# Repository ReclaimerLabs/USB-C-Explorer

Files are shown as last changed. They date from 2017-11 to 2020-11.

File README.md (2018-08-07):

# Introduction

The USB-C Explorer is a development board with everything needed to start working with USB Type-C. It contains a USB-C port controller and Power Delivery PHY chip, a microcontroller, and several options for user interaction. Here are the hardware features.

* [SAMD21E17A](https://www.microchip.com/wwwproducts/en/ATSAMD21E17) microcontroller
* [FUSB302B](http://www.onsemi.com/PowerSolutions/product.do?id=FUSB302B) USB PD PHY
* OLED Display
* Capacitive-sense slider
* Power header (up to 5 Amps)
* Debug port (UART and/or GPIO)
* SWD connector (Tag-Connect)
* Reset and User Buttons
* Onboard regulator, input up to 20 V.

# More Detail

The default firmware will identify as a USB Power Delivery Sink and list out all power capabilities from a corresponding Source. It will then request the highest power option. This voltage will be available on the power header. 

The default firmware also includes a USB bootloader. If you hold the User Button during reset, it will show up as a USB Mass Storage Device with a single file "FLASH.BIN". Copy the file to inspect the application firmware. Delete it and replace it with a new .bin file to rewrite the firmware. No programming cable is required.

To use the Single Wire Debug (SWD) function for live debugging, you will need a Tag-Connect TC2050-IDC-NL "plug of nails" cable and clip. You can then use an adapter to something like a Segger or J-Link.

This design is open source under an MIT license. All hardware designs, documentation, and firmware are freely available. You can find all design files at this github repository. I welcome feedback, so please let me know what you think. In particular, help with firmware would be appreciated. 

# Where to Buy

You can purchase a board [here](https://www.tindie.com/products/ReclaimerLabs/usb-c-explorer/). 

# Questions, Comments, and Contributions

Pull requests are welcome. If you have questions or comments, you can email me directly at jason@reclaimerlabs.com.

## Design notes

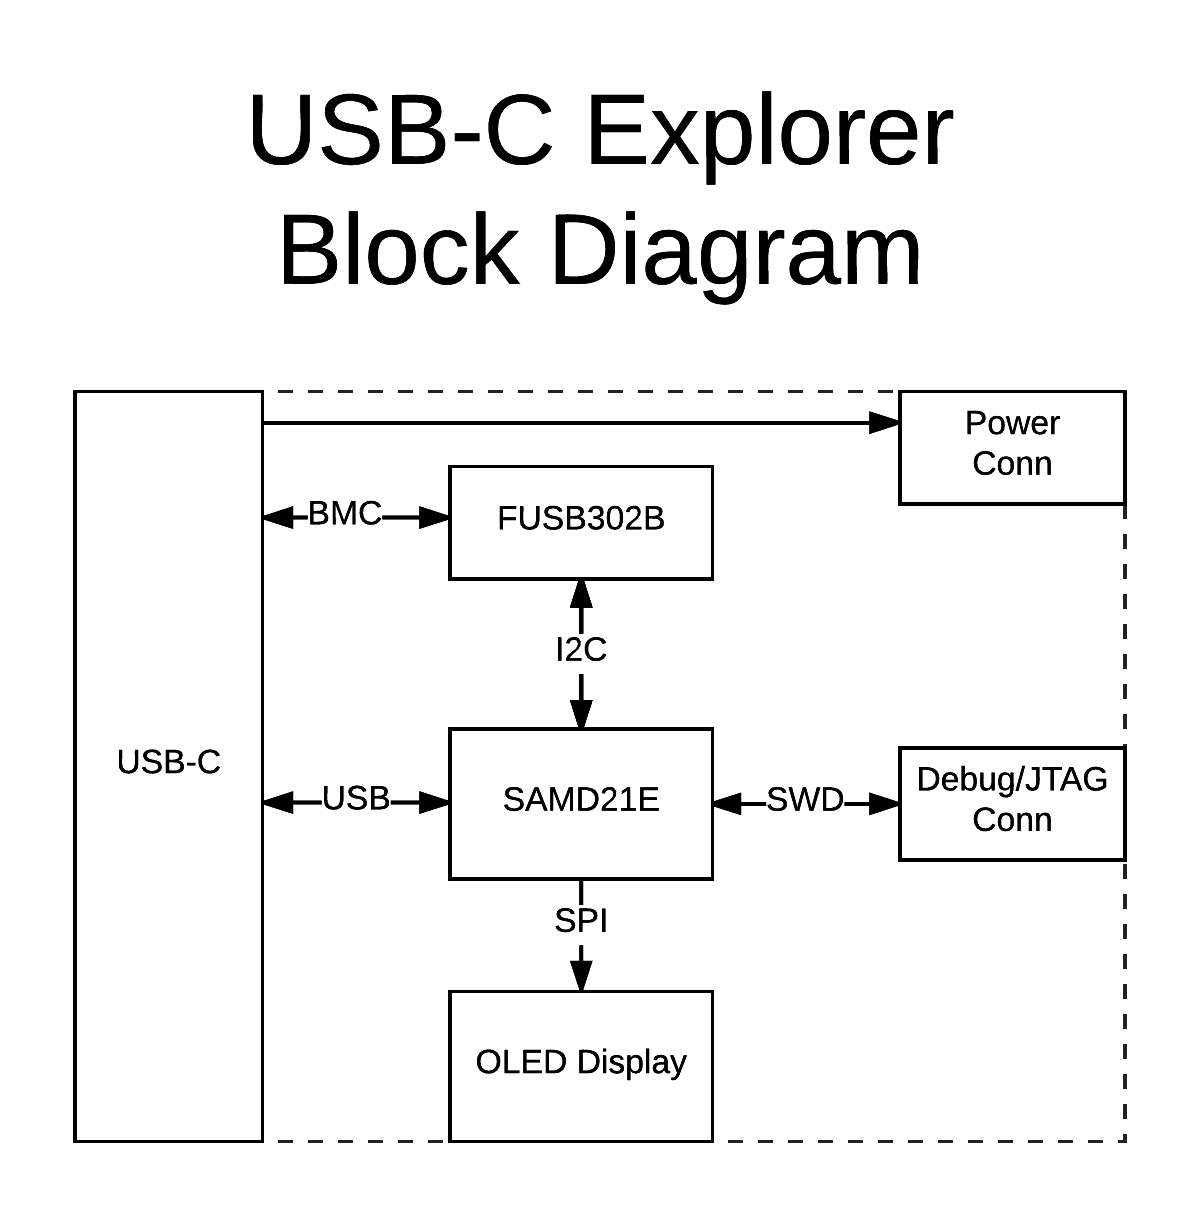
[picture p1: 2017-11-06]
electrical/img/USB-C Explorer Block Diagram.png

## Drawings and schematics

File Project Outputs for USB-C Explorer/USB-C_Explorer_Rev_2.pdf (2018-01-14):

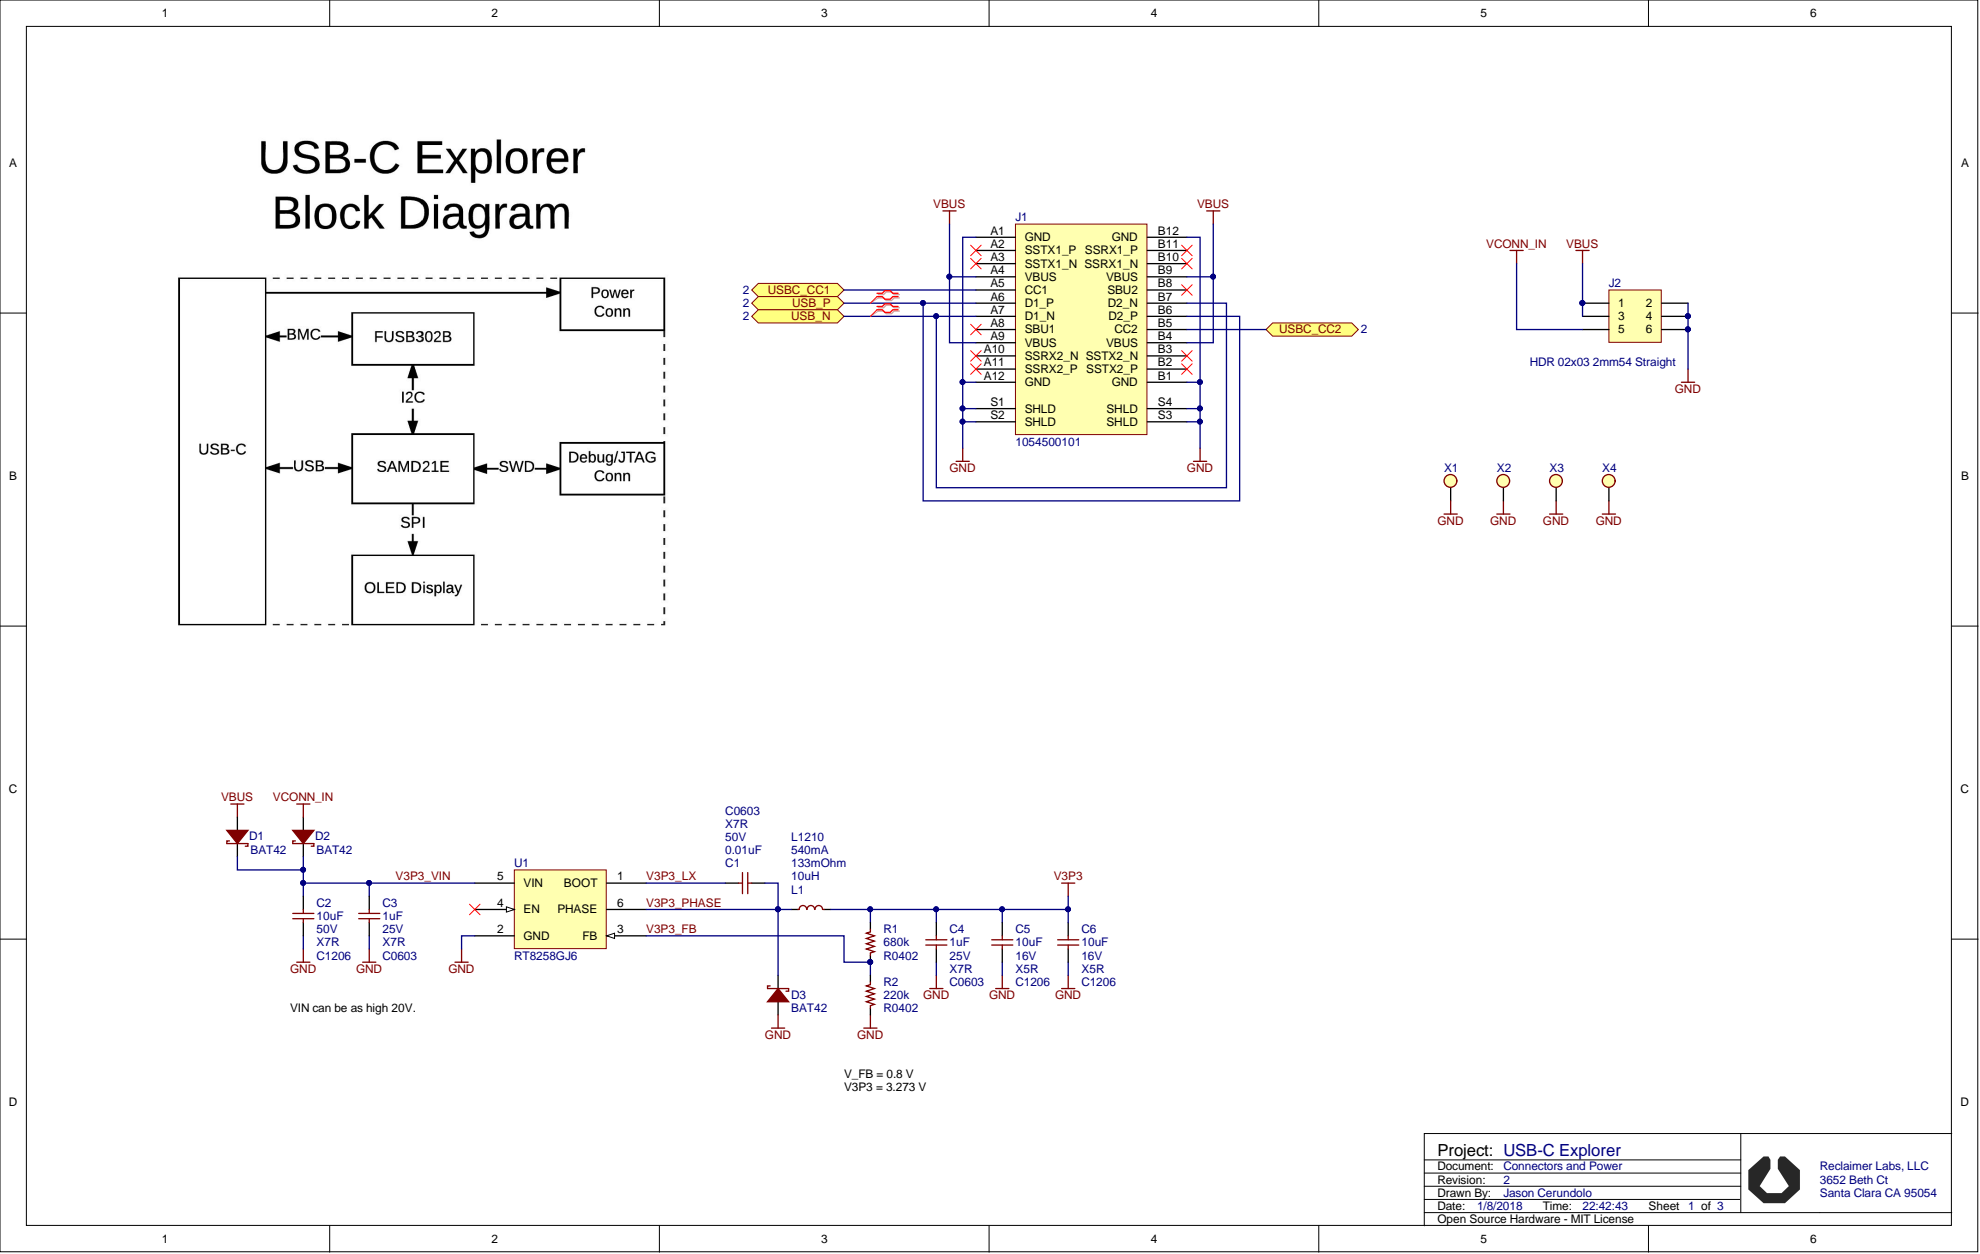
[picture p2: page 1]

VIN can be as high 20V.

Project:
Document: Connectors and Power
Revision:
Drawn By:
Date:
Open Source Hardware - MIT License

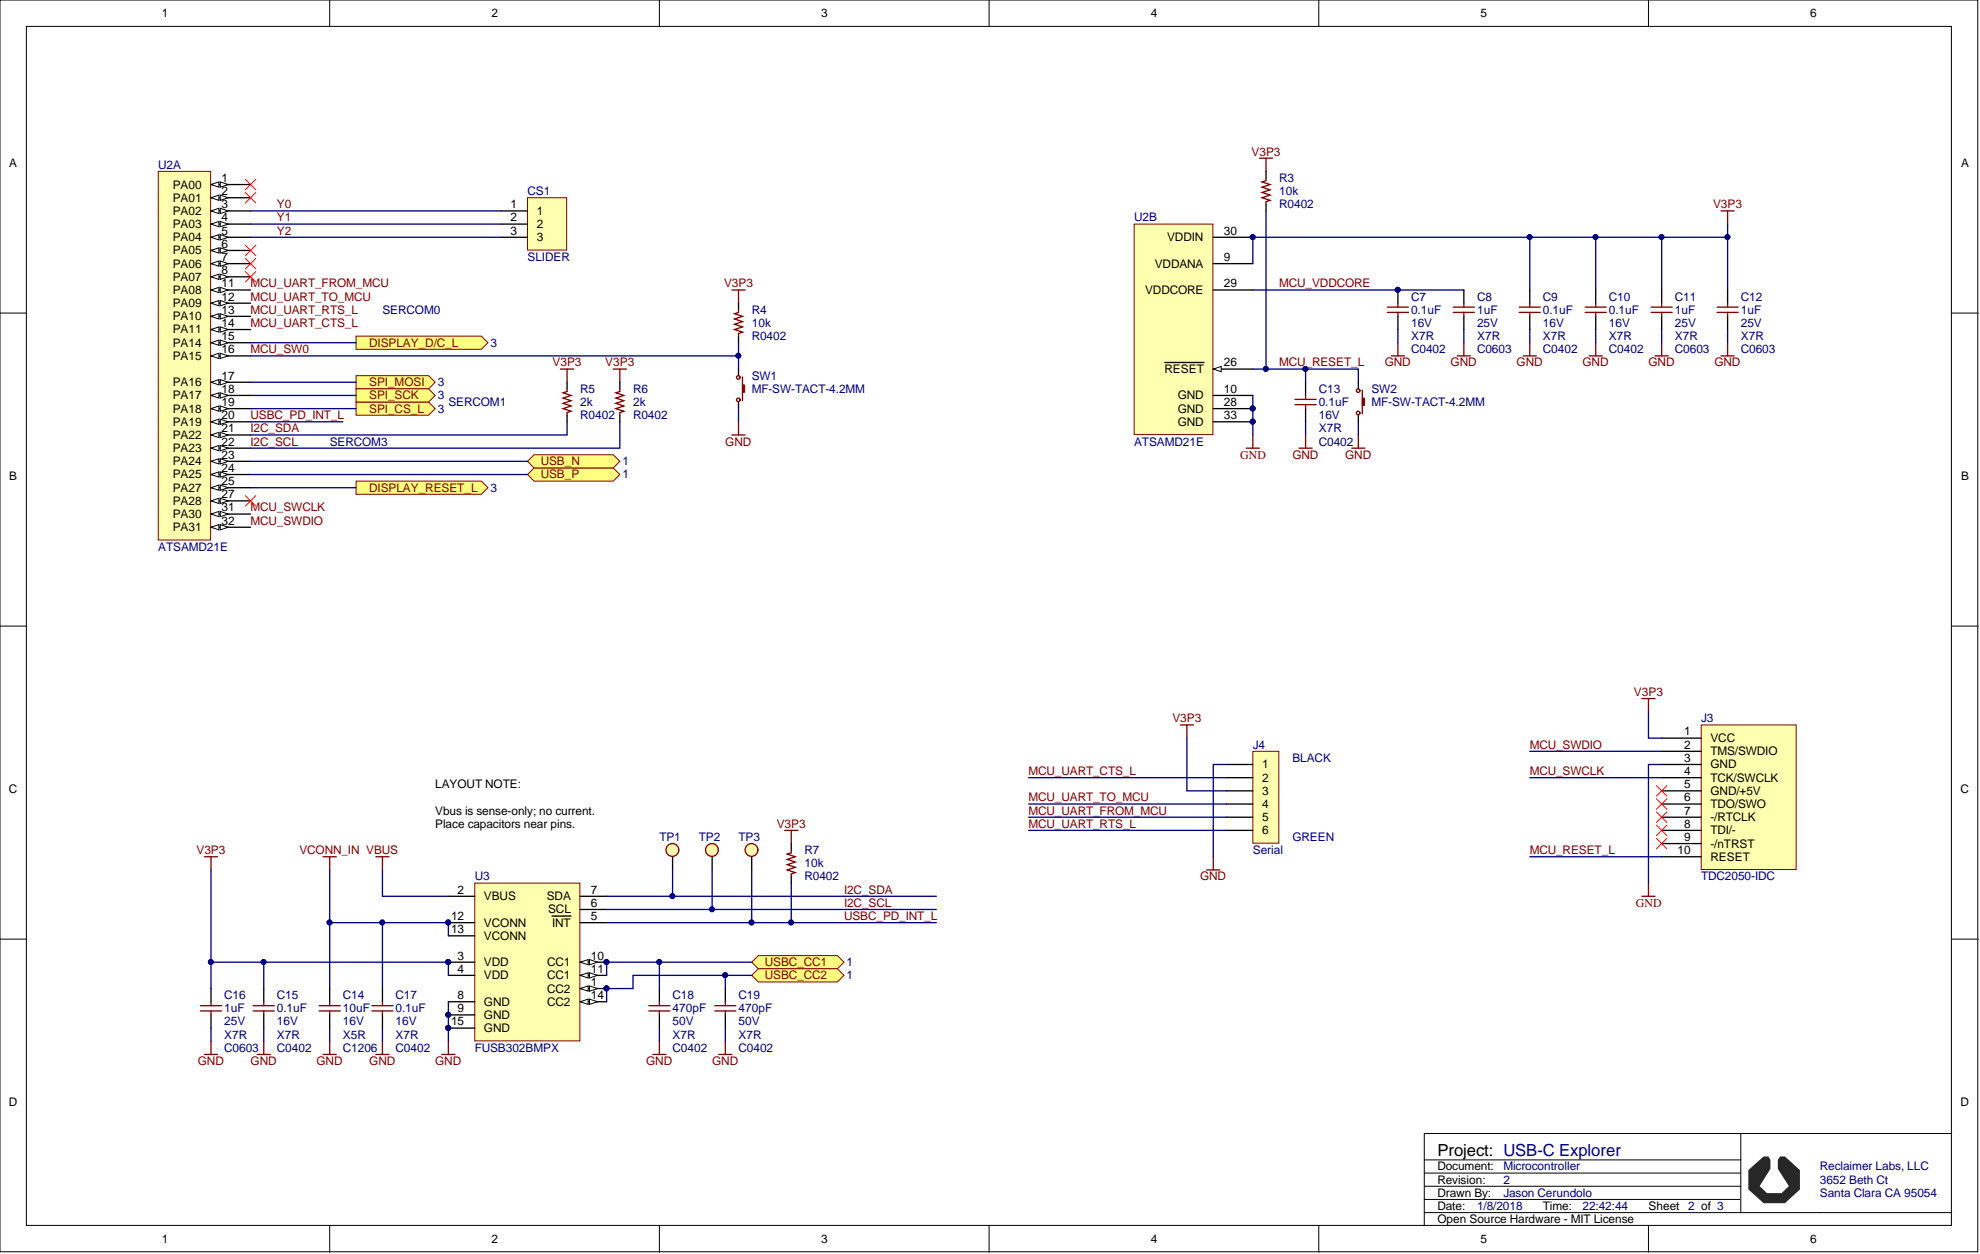
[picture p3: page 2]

Vbus is sense-only; no current.
Place capacitors near pins.

VDD 3

GND 8

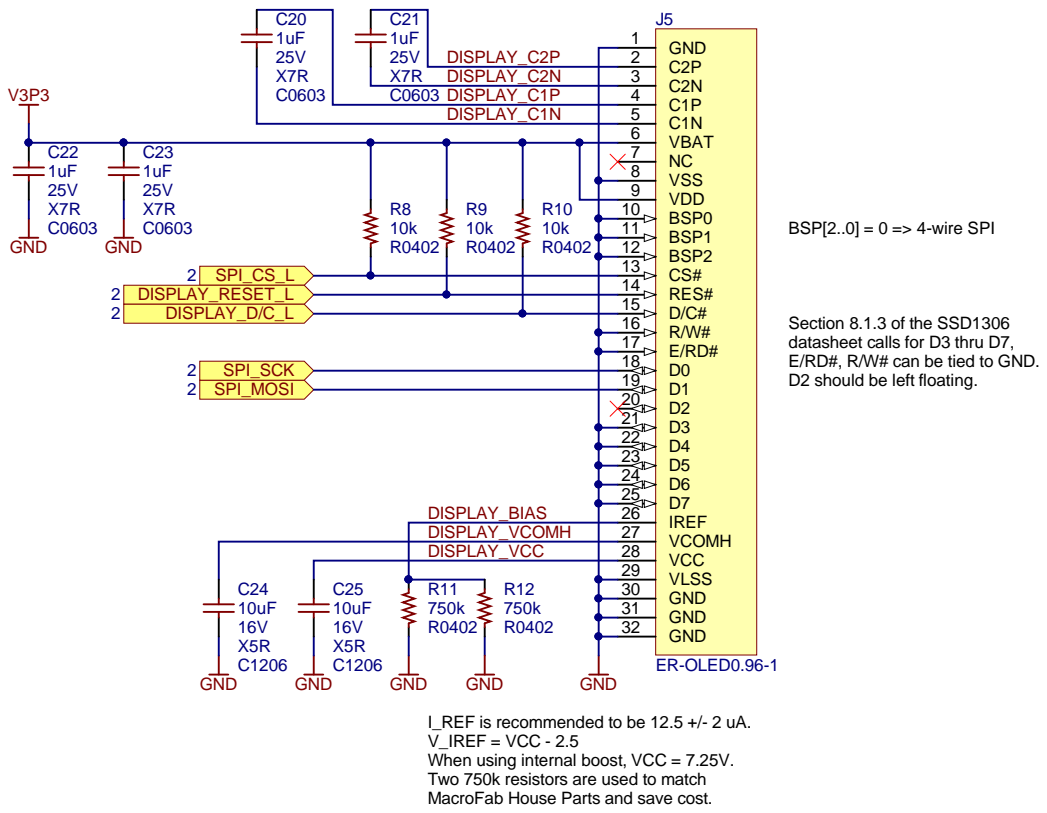
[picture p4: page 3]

C0603 | X7R DISPLAY_C2N | C2N 3

VDD 9

datasheet calls for D3 thru D7,
E/RD#, R/W# can be tied to GND.
D2 should be left floating.

IREF 26

DISPLAY_VCOMH | | | VCOMH 27
DISPLAY_VCC | | | VCC 28

VLSS 29
GND 30
GND 31
GND 32

I_REF is recommended to be 12.5 +/- 2 uA.
V_IREF = VCC - 2.5
When using internal boost, VCC = 7.25V.
Two 750k resistors are used to match
MacroFab House Parts and save cost.

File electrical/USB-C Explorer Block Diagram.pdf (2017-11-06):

# USB-C Explorer Block Diagram

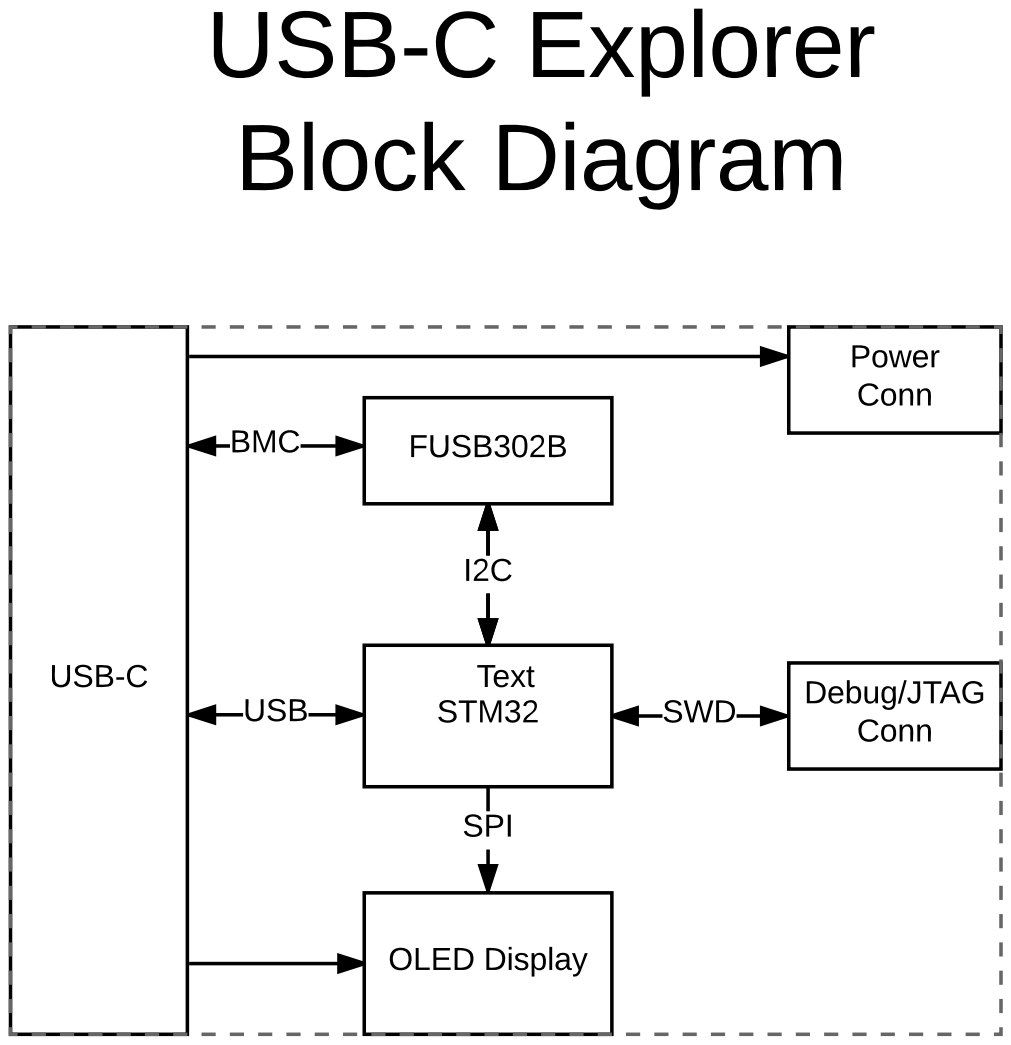
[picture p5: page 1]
USB-C; STM32; FUSB302B; OLED Display; Debug/JTAG Conn; Power Conn; BMC; USB; SWD; SPI; Text

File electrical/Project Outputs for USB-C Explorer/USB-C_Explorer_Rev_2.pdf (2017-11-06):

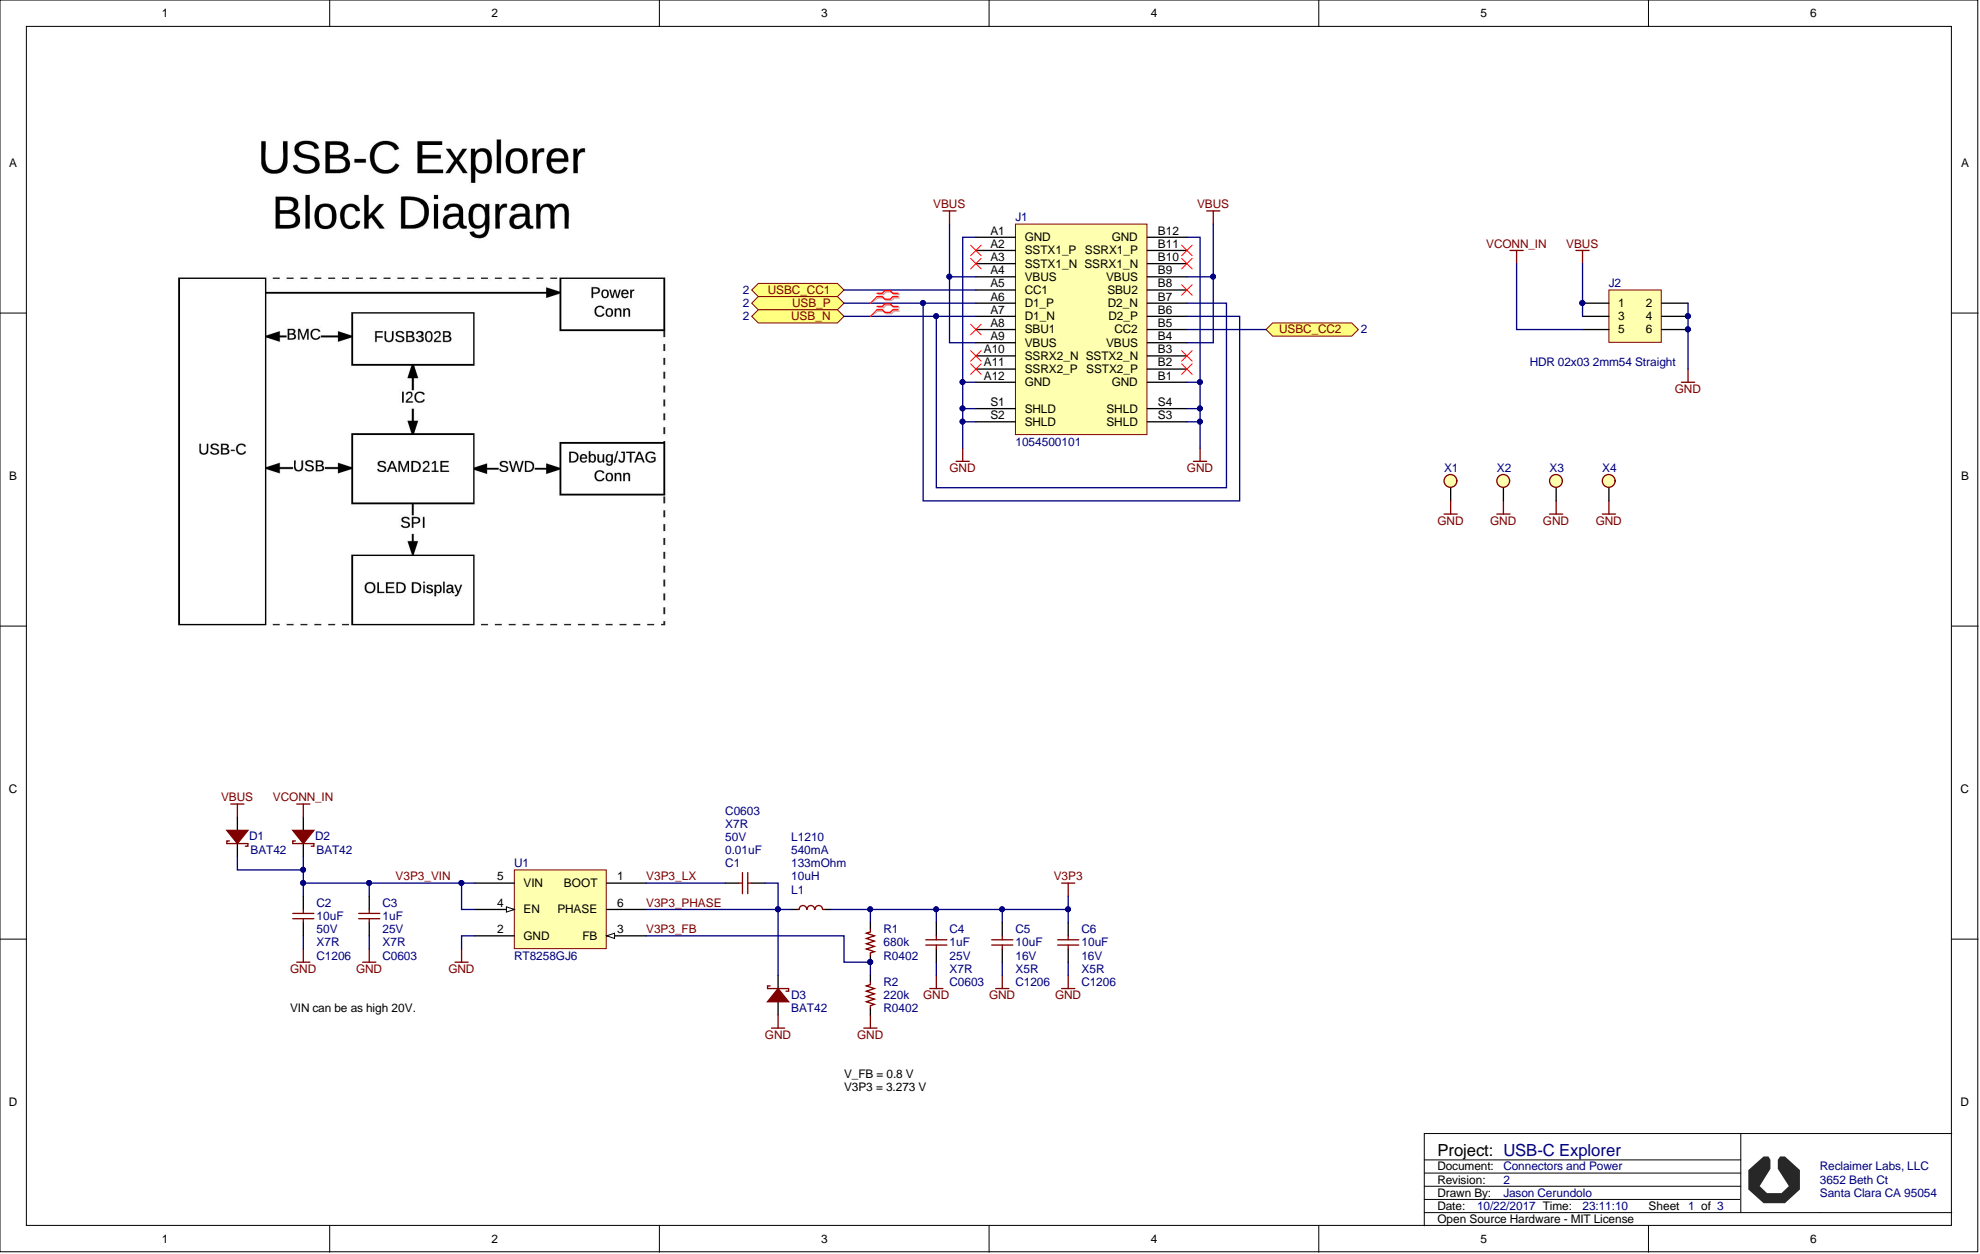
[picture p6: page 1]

VIN can be as high 20V.

Project:
Document: Connectors and Power
Revision:
Drawn By:
Date:
Open Source Hardware - MIT License

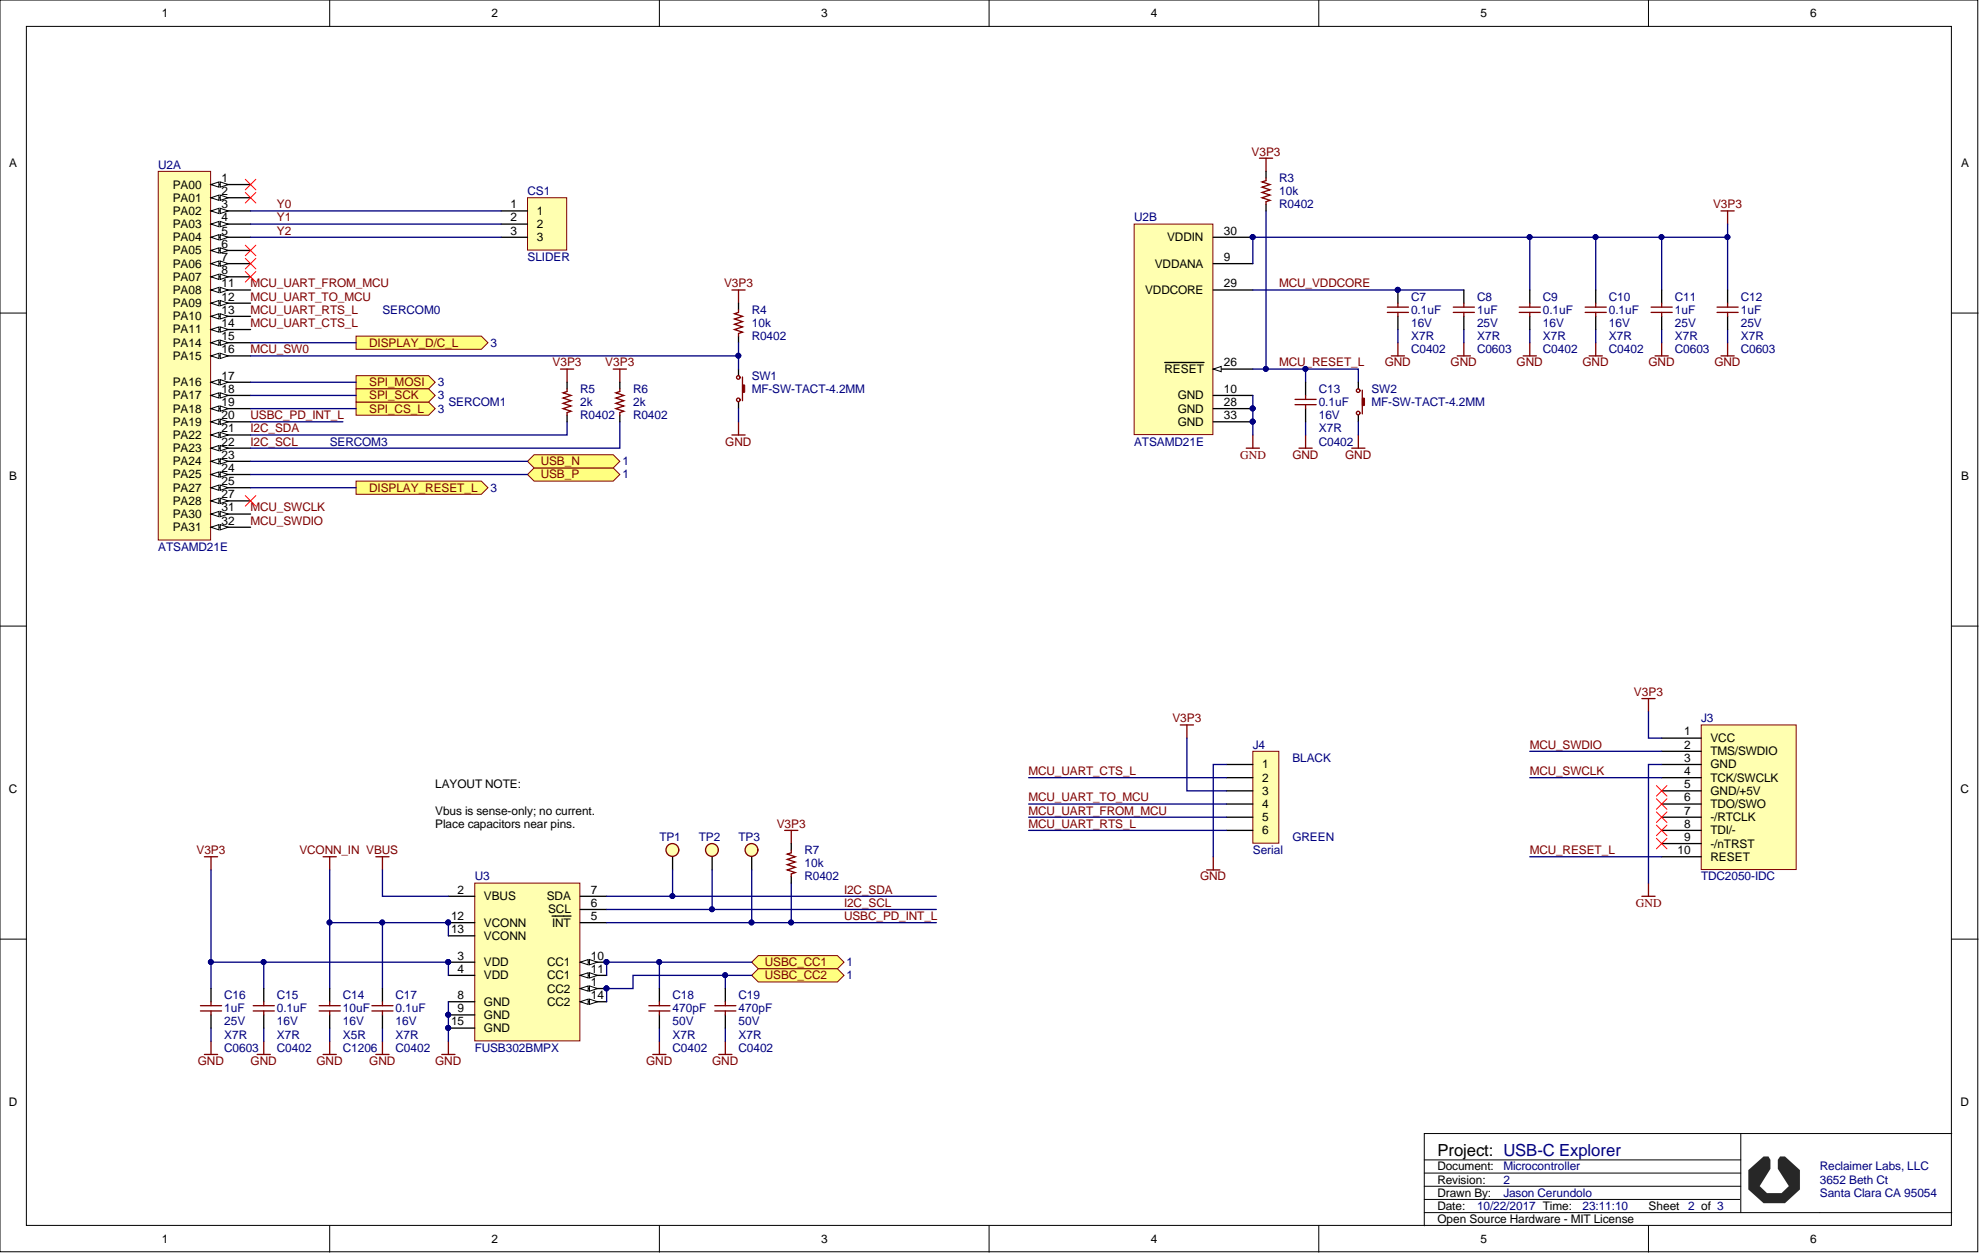
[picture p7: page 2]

Vbus is sense-only; no current.
Place capacitors near pins.

VDD 3

GND 8


C0603 | X7R DISPLAY_C2N | C2N 3

VDD 9

datasheet calls for D3 thru D7,
E/RD#, R/W# can be tied to GND.
D2 should be left floating.

IREF 26

DISPLAY_VCOMH | | | VCOMH 27
DISPLAY_VCC | | | VCC 28

VLSS 29
GND 30
GND 31
GND 32

I_REF is recommended to be 12.5 +/- 2 uA.
V_IREF = VCC - 2.5
When using internal boost, VCC = 7.25V.
Two 750k resistors are used to match
MacroFab House Parts and save cost.

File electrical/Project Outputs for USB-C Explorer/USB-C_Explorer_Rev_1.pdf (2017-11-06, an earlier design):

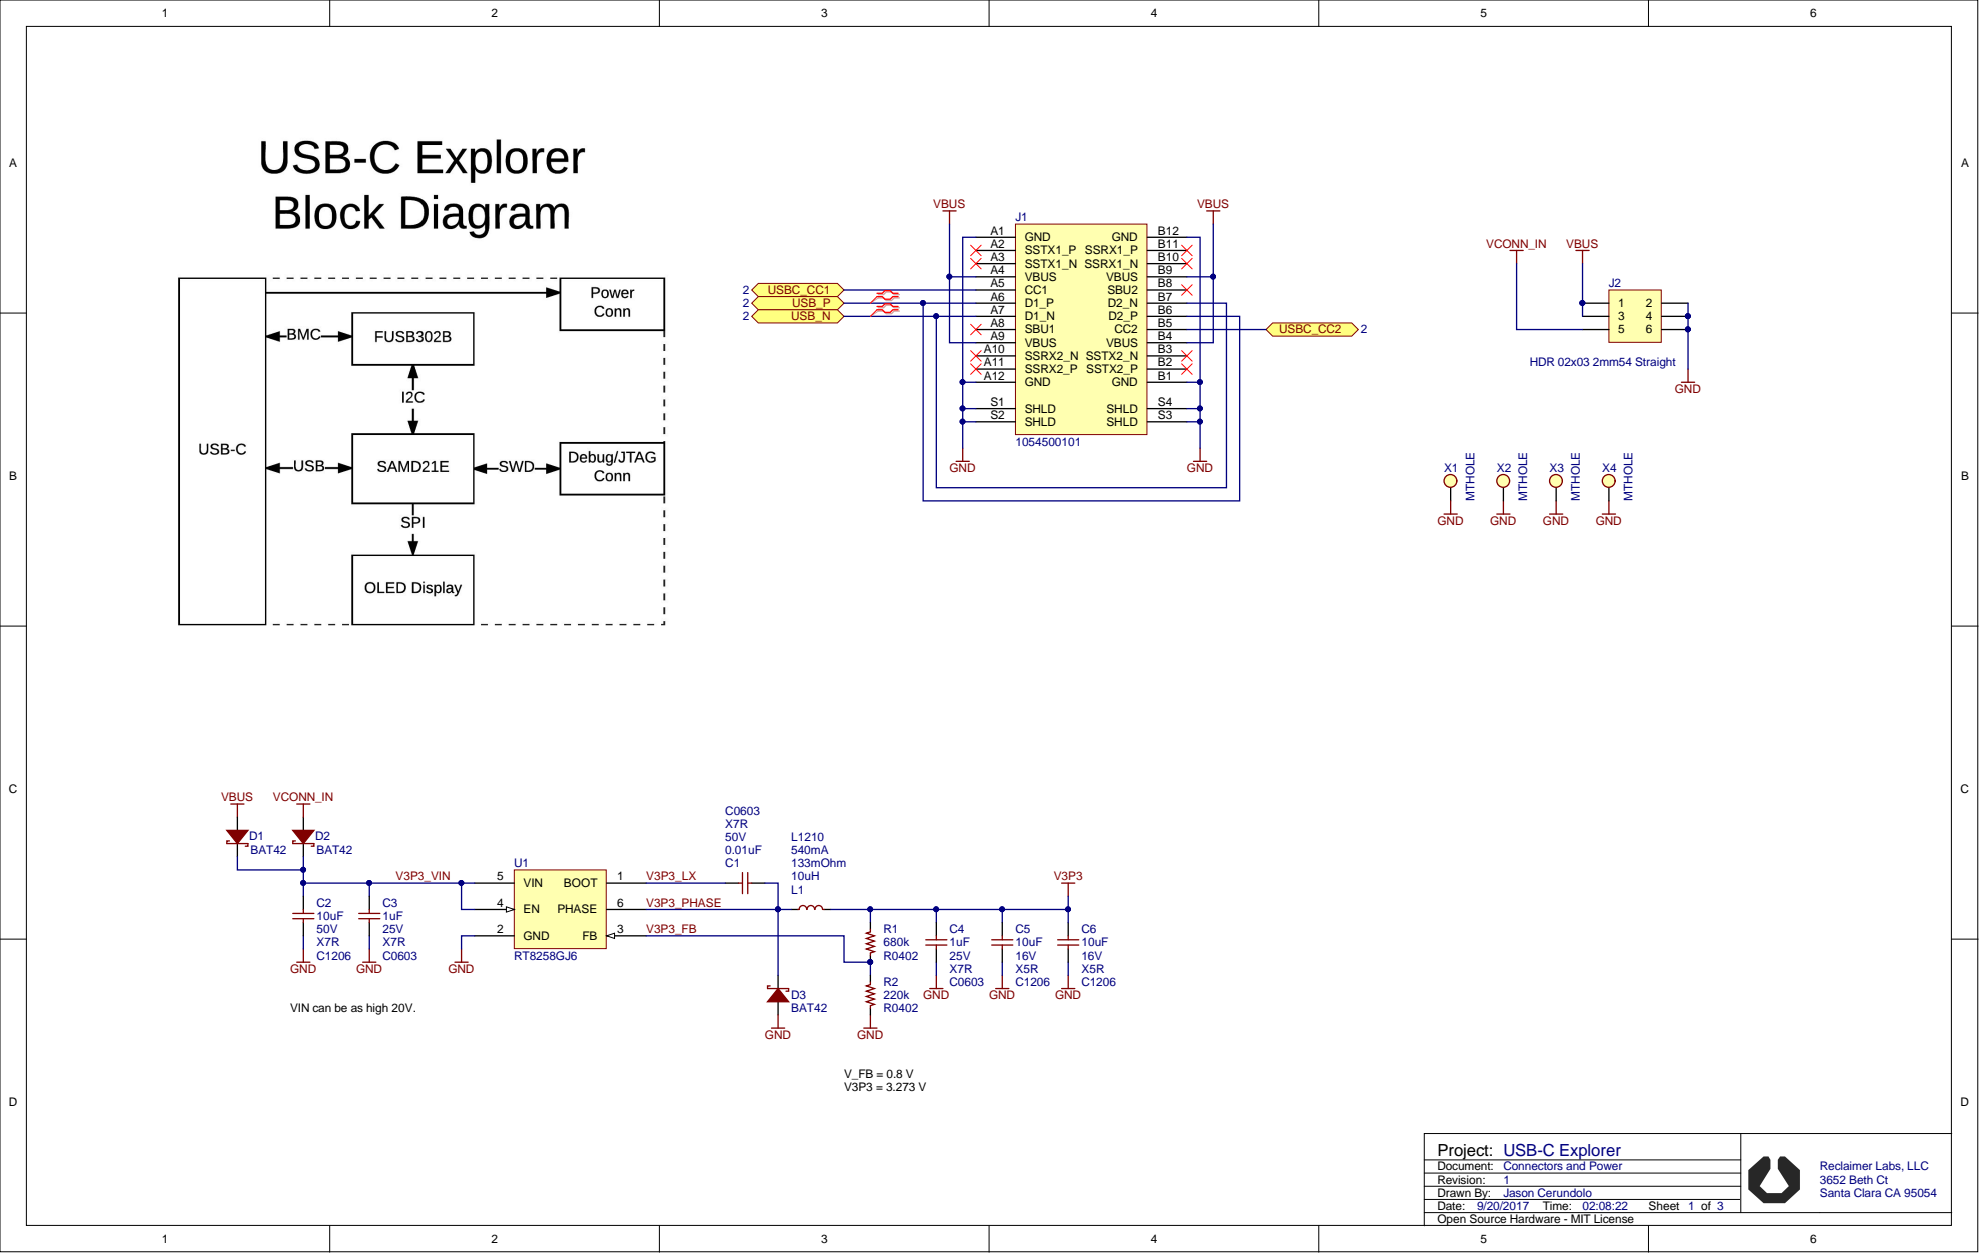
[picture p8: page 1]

VIN can be as high 20V.

Project:
Document: Connectors and Power
Revision:
Drawn By:
Date:
Open Source Hardware - MIT License

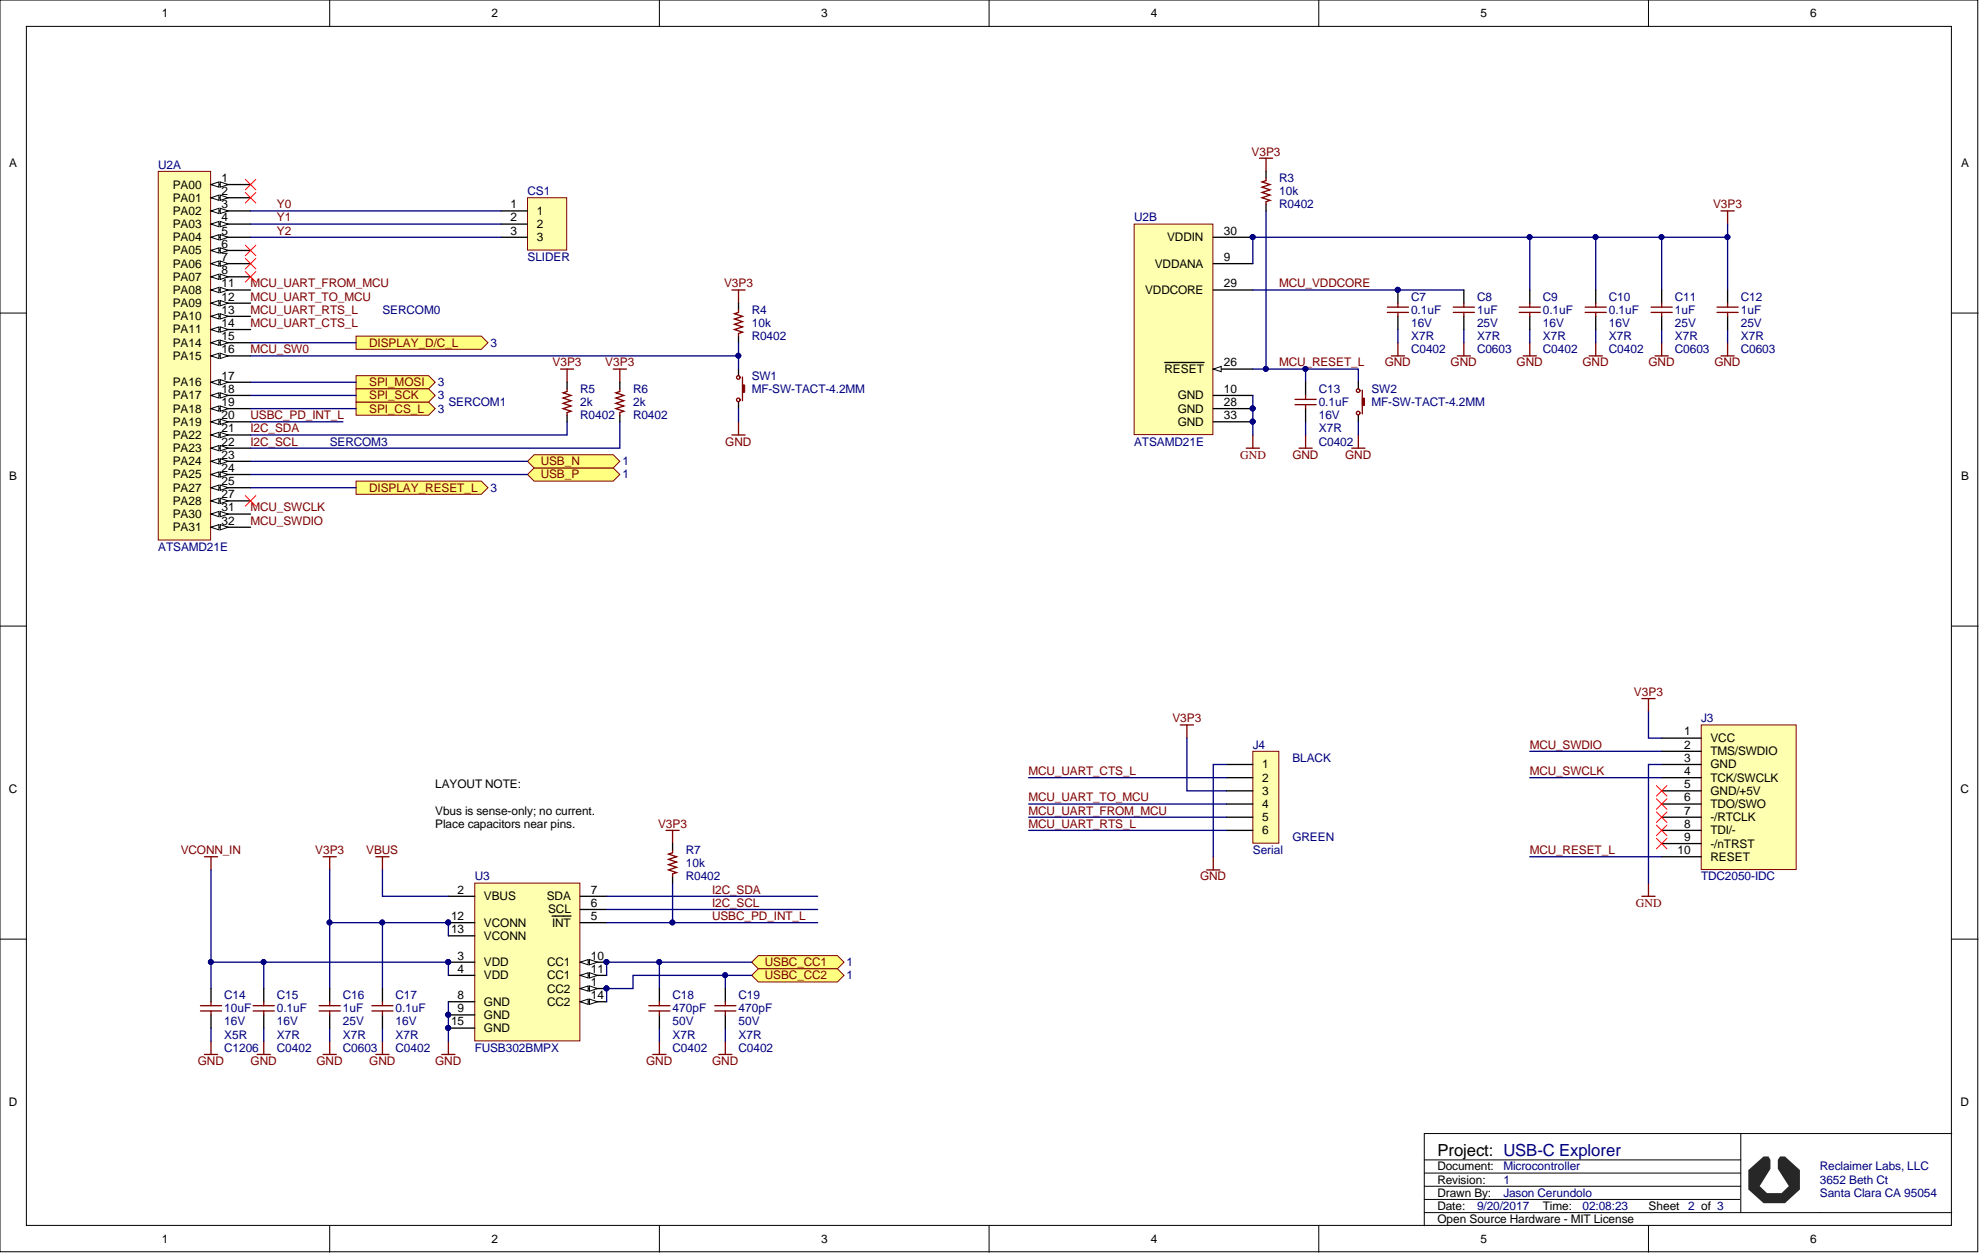
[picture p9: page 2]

Vbus is sense-only; no current.
Place capacitors near pins.

VDD 3

GND 8

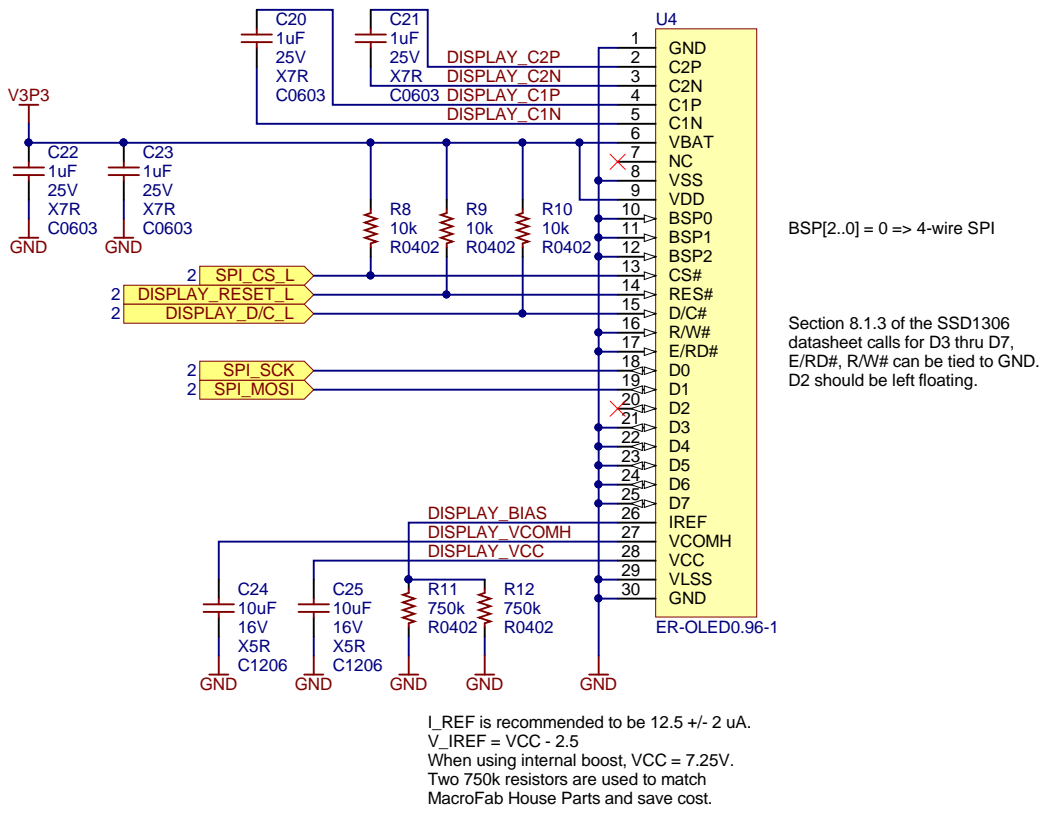
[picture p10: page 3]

C0603 | X7R DISPLAY_C2N | C2N 3

VDD 9

datasheet calls for D3 thru D7,
E/RD#, R/W# can be tied to GND.
D2 should be left floating.

IREF 26

DISPLAY_VCOMH | | | VCOMH 27
DISPLAY_VCC | | | VCC 28

VLSS 29

I_REF is recommended to be 12.5 +/- 2 uA.
V_IREF = VCC - 2.5
When using internal boost, VCC = 7.25V.
Two 750k resistors are used to match
MacroFab House Parts and save cost.

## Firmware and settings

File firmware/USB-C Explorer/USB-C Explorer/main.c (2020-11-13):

/* This source file is part of the ATMEL QTouch Library 5.0.8 */

/*****************************************************************************
 *
 * \file
 *
 * \brief  This file contains the SAMD QTouch library sample user application.
 *
 *
 * - Userguide:          QTouch Library Peripheral Touch Controller User Guide.
 * - Support email:      www.atmel.com/design-support/
 *
 *
 * Copyright (c) 2013-2015 Atmel Corporation. All rights reserved.
 *
 * \asf_license_start
 *
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
 * 3. The name of Atmel may not be used to endorse or promote products derived
 *    from this software without specific prior written permission.
 *
 * 4. This software may only be redistributed and used in connection with an
 *    Atmel microcontroller product.
 *
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
 * \asf_license_stop
 *
 ******************************************************************************/

/**
 * Include header files for all drivers that have been imported from
 * Atmel Software Framework (ASF).
 */
#include <asf.h>
// This should be included in asf.h, 
// but something went wrong moving to Microchip Studio
#include "touch_api_ptc.h"
#include "ugui.h"
#include "tcpm_driver.h"
#include "usb_pd_driver.h"

/**
 * Device Revision definition
 */
#define DEVICE_REVISION_MASK (0xFu << 8)
#define DEVICE_REVISION_MASK_POS (8u)
#define DEV_REV_A (0x0)
#define DEV_REV_B (0x1)
#define DEV_REV_C (0x2)

struct rtc_module rtc_instance;
struct tc_module tc_instance;
uint32_t g_us_timestamp_upper_32bit;
struct i2c_master_module i2c_master_instance;
uint32_t device_rev = 0;

// USB-C Specific - TCPM start 1
const struct tcpc_config_t tcpc_config[CONFIG_USB_PD_PORT_COUNT] = {
	{&i2c_master_instance, fusb302_I2C_SLAVE_ADDR, &fusb302_tcpm_drv},
};

int pd_count=0, pd_count_written=0;
uint32_t *pd_src_caps;
// USB-C Specific - TCPM end 1

volatile uint8_t display_screen, display_needs_update, display_change_requested;
uint8_t display_buffer[MAX_SCREENS][DISP_MEM_SIZE];
UG_GUI gui;
timestamp_t last_button_timestamp;

/*
 * switch_main_clock 
 */
void switch_main_clock(void);

/*! \brief Initialize timer
 *
 */
void rtc_init( void );

/*! \brief RTC timer overflow callback
 *
 */
void rtc_overflow_callback(void);

/*! \brief Configure the RTC timer callback
 *
 */
void configure_rtc_callbacks(void);

/*! \brief Configure the RTC timer count after which interrupts comes
 *
 */
void configure_rtc_count(void);

/*! \brief Set timer period.Called from Qdebug when application
 *     has to change the touch time measurement
 */
void set_timer_period(void);

/*! \brief RTC timer overflow callback
 *
 */
void rtc_overflow_callback(void)
{
	/* Do something on RTC overflow here */
	touch_time.time_to_measure_touch = 1;
	touch_time.current_time_ms = touch_time.current_time_ms +
			touch_time.measurement_period_ms;
}

/*! \brief Configure the RTC timer callback
 *
 */
void configure_rtc_callbacks(void)
{
	/* register callback */
	rtc_count_register_callback(&rtc_instance,
			rtc_overflow_callback, RTC_COUNT_CALLBACK_OVERFLOW);
	/* Enable callback */
	rtc_count_enable_callback(&rtc_instance, RTC_COUNT_CALLBACK_OVERFLOW);
}

/*! \brief Configure the RTC timer count after which interrupts comes
 *
 */
void configure_rtc_count(void)
{
	struct rtc_count_config config_rtc_count;
	rtc_count_get_config_defaults(&config_rtc_count);
    #if ((SAMC20) || (SAMC21))
	config_rtc_count.prescaler           = RTC_MODE0_CTRLA_PRESCALER_DIV32;
    #else
	config_rtc_count.prescaler           = RTC_MODE0_CTRL_PRESCALER_DIV2;
    #endif
	config_rtc_count.mode                = RTC_COUNT_MODE_16BIT;
	#ifdef FEATURE_RTC_CONTINUOUSLY_UPDATED
	config_rtc_count.continuously_update = true;
	#endif
	/* initialize rtc */
	rtc_count_init(&rtc_instance, RTC, &config_rtc_count);

	/* enable rtc */
	rtc_count_enable(&rtc_instance);
}

/*! \brief Initialize timer
 *
 */
void rtc_init(void)
{
	/* Configure and enable RTC */
	configure_rtc_count();

	/* Configure and enable callback */
	configure_rtc_callbacks();

	/* Set Timer Period */

	rtc_count_set_period(&rtc_instance, DEF_TOUCH_MEASUREMENT_PERIOD_MS);
}

/*! \brief Set timer period.Called from Qdebug when application
 *     has to change the touch time measurement
 */
void set_timer_period(void )
{
	rtc_count_set_period(&rtc_instance, touch_time.measurement_period_ms);
}

void display_init(void);
void display_set_pixel(UG_S16 x, UG_S16 y, UG_COLOR color);
void i2c_init(void);
void timer_init(void);
void tc_callback_overflow(void);
void measure_nonPD_current(void);
void extint_detection_callback(void);

/*! \brief Main function
 *
 */
int main(void)
{
	system_init();
	irq_initialize_vectors();
	cpu_irq_enable();
	ioport_init();
	delay_init();
	rtc_init();
	touch_sensors_init();
	system_interrupt_enable_global();
	
	display_init();
	i2c_init();
	timer_init();
	delay_ms(50);
	// USB-C Specific - TCPM start 2
	tcpm_init(0);
	delay_ms(50);
	pd_init(0);
	delay_ms(50);
	ioport_set_pin_dir(USBC_INT_PIN, IOPORT_DIR_INPUT);
	// USB-C Specific - TCPM end 2
	
	//system_set_sleepmode(SYSTEM_SLEEPMODE_STANDBY);
	
	measure_nonPD_current();
	delay_ms(50);

	// Start USB stack to authorize VBus monitoring
	udc_start();

	while (1) {
		touch_sensors_measure();
		
		if (!ioport_get_pin_level(USBC_INT_PIN)) {
			tcpc_alert(0);
		}
		
		if (display_change_requested)
		{
			if (display_screen >= (MAX_SCREENS - 1))
			{
				display_screen = 0;
			}
			else
			{
				display_screen++;
			}
			display_change_requested = 0;
			display_needs_update = 1;
		}
		
		if (display_needs_update)
		{
			ssd1306_write_data_n(display_buffer[display_screen], DISP_MEM_SIZE);
			display_needs_update = 0;
		}

		// This is set so as not to needlessly spam the I2C bus
		delay_us(1000);
		
		// See the notes in pd_process_source_cap_callback()
		if (pd_count_written < pd_count)
		{
			char str[256];
			uint32_t ma, mv, pdo;
			
			pd_extract_pdo_power(pd_src_caps[pd_count_written], &ma, &mv);
			sprintf(str, "%5.2f V, %5.2f A", (float)mv/1000, (float)ma/1000);
			UG_PutString(0, 8*(pd_count_written+2), str);
			pd_count_written++;
			display_needs_update = 1;
		}
		
		pd_run_state_machine(0);
	}
}

void display_init(void)
{
	char str[256];
	
	ssd1306_init();

	// 1/64 Duty (0x0F~0x3F)
	ssd1306_write_command(SSD1306_CMD_SET_MULTIPLEX_RATIO);
	ssd1306_write_command(0x3F);

	//ssd1306_write_command(SSD1306_CMD_SET_COM_OUTPUT_SCAN_UP);

	// Set COM Pins hardware configuration, based on example from display datasheet
	ssd1306_write_command(SSD1306_CMD_SET_COM_PINS);
	ssd1306_write_command(0x12);

	// set horizontal addressing mode
	ssd1306_write_command(SSD1306_CMD_SET_MEMORY_ADDRESSING_MODE);
	ssd1306_write_command(1);

	// set contrast, based on example from display datasheet
	ssd1306_write_command(SSD1306_CMD_SET_CONTRAST_CONTROL_FOR_BANK0);
	ssd1306_write_command(0xCF);

	// set normal display
	ssd1306_write_command(SSD1306_CMD_SET_NORMAL_DISPLAY);
	
	UG_Init(&gui, display_set_pixel, 128, 64);
	UG_SelectGUI(&gui);
	UG_FontSelect(&FONT_6X8);
	
	int i;
	for(i=0; i < MAX_SCREENS; i++)
	{
		memset(display_buffer[i], 0x00, DISP_MEM_SIZE);
		ssd1306_write_data_n(display_buffer[i], DISP_MEM_SIZE);
	}
		
	display_screen = SCREEN_ALTMODE;
	sprintf(str, "No Alt Mode");
	UG_PutString(0, 8, str);
	display_screen = SCREEN_POWER;
	
	display_needs_update = 1;
	display_screen = 0;
	display_change_requested = 0;
	struct extint_chan_conf config_extint_chan;
	extint_chan_get_config_defaults(&config_extint_chan);
	config_extint_chan.gpio_pin           = SW_USER_EIC_PIN;
	config_extint_chan.gpio_pin_mux       = SW_USER_EIC_MUX;
	config_extint_chan.gpio_pin_pull      = EXTINT_PULL_UP;
	config_extint_chan.detection_criteria = EXTINT_DETECT_FALLING;
	extint_chan_set_config(SW_USER_EIC_LINE, &config_extint_chan);
	last_button_timestamp.val = 0;
	extint_register_callback(extint_detection_callback,
		SW_USER_EIC_LINE,
		EXTINT_CALLBACK_TYPE_DETECT);
	extint_chan_enable_callback(SW_USER_EIC_LINE,
		EXTINT_CALLBACK_TYPE_DETECT);
}

void extint_detection_callback(void)
{
	timestamp_t t_now;
	system_interrupt_enter_critical_section();
	t_now.le.lo = tc_get_count_value(&tc_instance);
	t_now.le.hi = g_us_timestamp_upper_32bit;
	system_interrupt_leave_critical_section();
	
	// if it's been less than 25 ms, ignore it
	if ((t_now.val - last_button_timestamp.val) < 25000)
	{
		return;
	}
	else
	{
		if (port_pin_get_input_level(SW_USER_EIC_PIN) == false)
		{
			display_change_requested = 1;
		}
	}
}

void display_set_pixel(UG_S16 x, UG_S16 y, UG_COLOR color)
{
	if ((x >= DISP_SIZE_X) || (y >= DISP_SIZE_Y) || (x < 0) || (y < 0))
	{
		return; // error
	}
	
	if (color)
	{
		display_buffer[display_screen][((x*DISP_SIZE_X)>>4) + (y>>3)] |= (1<<(y%8));
	}
	else
	{
		display_buffer[display_screen][((x*DISP_SIZE_X)>>4) + (y>>3)] &= ~(1<<(y%8));
	}
}

void i2c_init(void)
{
	struct i2c_master_config config_i2c_master;
	i2c_master_get_config_defaults(&config_i2c_master);
	config_i2c_master.buffer_timeout = 10000;
	config_i2c_master.baud_rate = I2C_MASTER_BAUD_RATE_1000KHZ;
	config_i2c_master.pinmux_pad0 = I2C_SDA_PINMUX;
	config_i2c_master.pinmux_pad1 = I2C_SCL_PINMUX;
	i2c_master_init(&i2c_master_instance, I2C_MODULE, &config_i2c_master);
	i2c_master_enable(&i2c_master_instance);
}

void timer_init(void)
{
	struct tc_config config_tc;
	tc_get_config_defaults(&config_tc);

	config_tc.clock_source    = GCLK_GENERATOR_4;
	config_tc.counter_size    = TC_COUNTER_SIZE_32BIT;
	config_tc.clock_prescaler = TC_CLOCK_PRESCALER_DIV1;
	config_tc.run_in_standby  = true;

	tc_init(&tc_instance, TC_TIMESTAMP, &config_tc);

	g_us_timestamp_upper_32bit = 0;
	tc_enable(&tc_instance);
	
	tc_register_callback(
		&tc_instance, 
		tc_callback_overflow, 
		TC_CALLBACK_CC_CHANNEL0);

	tc_enable_callback(&tc_instance, TC_CALLBACK_CC_CHANNEL0);
}

void tc_callback_overflow(void)
{
	g_us_timestamp_upper_32bit++;
}

void measure_nonPD_current(void)
{
	char str[256];
	int cc1, cc2;
	
	cc1 = 0;
	cc2 = 0;
	tcpm_get_cc(0, &cc1, &cc2);
	
	sprintf(str, "Non-PD Current");
	UG_PutString(0, 8, str);
	if ((cc1 == TYPEC_CC_VOLT_SNK_DEF) || (cc2 == TYPEC_CC_VOLT_SNK_DEF))
	{
		// Primary Detection
		// Drive DP high, measure DM
		// If low, regular port, otherwise some sort of charging port
		ioport_set_pin_dir(USB20_DP_PIN, IOPORT_DIR_OUTPUT);
		ioport_set_pin_level(USB20_DP_PIN, IOPORT_PIN_LEVEL_HIGH);
		ioport_set_pin_dir(USB20_DM_PIN, IOPORT_DIR_INPUT);
		//ioport_set_pin_mode(USB20_DP_PIN, IOPORT_MODE_PULLUP);
		delay_ms(1);
		bool usb_dp_value = ioport_get_pin_level(USB20_DM_PIN);
		if (usb_dp_value == IOPORT_PIN_LEVEL_HIGH)
		{
			// Some sort of charging port
			// Drive DM high, measure DP
			// If high, Dedicated Charging Port, otherwise, Charging Downstream Port
			ioport_set_pin_dir(USB20_DM_PIN, IOPORT_DIR_OUTPUT);
			ioport_set_pin_level(USB20_DM_PIN, IOPORT_PIN_LEVEL_HIGH);
			ioport_set_pin_dir(USB20_DP_PIN, IOPORT_DIR_INPUT);
			bool usb_dp_value = ioport_get_pin_level(USB20_DP_PIN);
			if (usb_dp_value == IOPORT_PIN_LEVEL_HIGH)
			{
				sprintf(str, "Dedicated Charging Port");
			}
			else
			{
				sprintf(str, "Charging Downstream Port");
			}
		} 
		else
		{
			sprintf(str, "Default USB Power");
		}
	}
	else if ((cc1 == TYPEC_CC_VOLT_SNK_1_5) || (cc2 == TYPEC_CC_VOLT_SNK_1_5))
	{
		sprintf(str, "Type-C 1.5 A");
	}
	else if ((cc1 == TYPEC_CC_VOLT_SNK_3_0) || (cc2 == TYPEC_CC_VOLT_SNK_3_0))
	{
		sprintf(str, "Type-C 3.0 A");
	}
	else
	{
		sprintf(str, "Unknown Error");
	}
	UG_PutString(0, 16, str);
	ssd1306_write_data_n(display_buffer[display_screen], DISP_MEM_SIZE);
}

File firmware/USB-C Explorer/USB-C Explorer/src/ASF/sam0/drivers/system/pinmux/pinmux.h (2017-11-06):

/**
 * \file
 *
 * \brief SAM Pin Multiplexer Driver
 *
 * Copyright (C) 2012-2015 Atmel Corporation. All rights reserved.
 *
 * \asf_license_start
 *
 * \page License
 *
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
 * 3. The name of Atmel may not be used to endorse or promote products derived
 *    from this software without specific prior written permission.
 *
 * 4. This software may only be redistributed and used in connection with an
 *    Atmel microcontroller product.
 *
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
 * \asf_license_stop
 *
 */
/*
 * Support and FAQ: visit <a href="http://www.atmel.com/design-support/">Atmel Support</a>
 */
#ifndef PINMUX_H_INCLUDED
#define PINMUX_H_INCLUDED

/**
 * \defgroup asfdoc_sam0_system_pinmux_group SAM System Pin Multiplexer (SYSTEM PINMUX) Driver
 *
 * This driver for Atmel&reg; | SMART ARM&reg;-based microcontrollers provides
 * an interface for the configuration and management of the device's physical
 * I/O Pins, to alter the direction and input/drive characteristics as well as
 * to configure the pin peripheral multiplexer selection.
 *
 * The following peripheral is used by this module:
 *  - PORT (Port I/O Management)
 *
 * The following devices can use this module:
 *  - Atmel | SMART SAM D20/D21
 *  - Atmel | SMART SAM R21
 *  - Atmel | SMART SAM D09/D10/D11
 *  - Atmel | SMART SAM L21/L22
 *  - Atmel | SMART SAM DA1
 *  - Atmel | SMART SAM C20/C21
 *
 * The outline of this documentation is as follows:
 *  - \ref asfdoc_sam0_system_pinmux_prerequisites
 *  - \ref asfdoc_sam0_system_pinmux_module_overview
 *  - \ref asfdoc_sam0_system_pinmux_special_considerations
 *  - \ref asfdoc_sam0_system_pinmux_extra_info
 *  - \ref asfdoc_sam0_system_pinmux_examples
 *  - \ref asfdoc_sam0_system_pinmux_api_overview
 *
 *
 * \section asfdoc_sam0_system_pinmux_prerequisites Prerequisites
 *
 * There are no prerequisites for this module.
 *
 *
 * \section asfdoc_sam0_system_pinmux_module_overview Module Overview
 *
 * The SAM devices contain a number of General Purpose I/O pins, used to
 * interface the user application logic and internal hardware peripherals to
 * an external system. The Pin Multiplexer (PINMUX) driver provides a method
 * of configuring the individual pin peripheral multiplexers to select
 * alternate pin functions.
 *
 * \subsection asfdoc_sam0_system_pinmux_features Driver Feature Macro Definition
 * <table>
 *  <tr>
 *    <th>Driver Feature Macro</th>
 *    <th>Supported devices</th>
 *  </tr>
 *  <tr>
 *    <td>FEATURE_SYSTEM_PINMUX_DRIVE_STRENGTH</td>
 *    <td>SAM L21, SAM C20/C21</td>
 *  </tr>
 * </table>
 * \note The specific features are only available in the driver when the
 * selected device supports those features.
 *
 * \subsection asfdoc_sam0_system_pinmux_physical_logical_pins Physical and Logical GPIO Pins
 * SAM devices use two naming conventions for the I/O pins in the device; one
 * physical and one logical. Each physical pin on a device package is assigned
 * both a physical port and pin identifier (e.g. "PORTA.0") as well as a
 * monotonically incrementing logical GPIO number (e.g. "GPIO0"). While the
 * former is used to map physical pins to their physical internal device module
 * counterparts, for simplicity the design of this driver uses the logical GPIO
 * numbers instead.
 *
 * \subsection asfdoc_sam0_system_pinmux_peripheral_muxing Peripheral Multiplexing
 * SAM devices contain a peripheral MUX, which is individually controllable
 * for each I/O pin of the device. The peripheral MUX allows you to select the
 * function of a physical package pin - whether it will be controlled as a user
 * controllable GPIO pin, or whether it will be connected internally to one of
 * several peripheral modules (such as an I<SUP>2</SUP>C module). When a pin is
 * configured in GPIO mode, other peripherals connected to the same pin will be
 * disabled.
 *
 * \subsection asfdoc_sam0_system_pinmux_pad_characteristics Special Pad Characteristics
 * There are several special modes that can be selected on one or more I/O pins
 * of the device, which alter the input and output characteristics of the pad.
 *
 * \subsubsection asfdoc_sam0_system_pinmux_drive_strength Drive Strength
 * The Drive Strength configures the strength of the output driver on the
 * pad. Normally, there is a fixed current limit that each I/O pin can safely
 * drive, however some I/O pads offer a higher drive mode which increases this
 * limit for that I/O pin at the expense of an increased power consumption.
 *
 * \subsubsection asfdoc_sam0_system_pinmux_slew_rate Slew Rate
 * The Slew Rate configures the slew rate of the output driver, limiting the
 * rate at which the pad output voltage can change with time.
 *
 * \subsubsection asfdoc_sam0_system_pinmux_input_sample_mode Input Sample Mode
 * The Input Sample Mode configures the input sampler buffer of the pad. By
 * default, the input buffer is only sampled "on-demand", i.e. when the user
 * application attempts to read from the input buffer. This mode is the most
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

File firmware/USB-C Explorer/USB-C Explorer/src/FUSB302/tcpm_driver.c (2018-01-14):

/*
 * tcpm_driver.c
 *
 * Created: 11/11/2017 18:42:26
 *  Author: jason
 */ 

#include "tcpm_driver.h"

extern const struct tcpc_config_t tcpc_config[CONFIG_USB_PD_PORT_COUNT];

/* I2C wrapper functions - get I2C port / slave addr from config struct. */
int tcpc_write(int port, int reg, int val)
{
	uint8_t data[2];
	data[0] = (0xFF) & reg;
	data[1] = (0xFF) & val;
	
	struct i2c_master_packet packet;
	packet.address = tcpc_config[port].i2c_slave_addr;
	packet.data_length = 2;
	packet.data = data;
	packet.ten_bit_address = false;
	packet.high_speed = false;
	packet.hs_master_code = 0x00;
	
	return i2c_master_write_packet_wait(&i2c_master_instance, &packet);
}

int tcpc_write16(int port, int reg, int val)
{
	uint8_t data[3];
	data[0] = (0xFF) & reg;
	data[1] = (0xFF) & val;
	data[2] = (0xFF) & (val >> 8);
	
	struct i2c_master_packet packet;
	packet.address = tcpc_config[port].i2c_slave_addr;
	packet.data_length = 3;
	packet.data = data;
	packet.ten_bit_address = false;
	packet.high_speed = false;
	packet.hs_master_code = 0x00;
	
	return i2c_master_write_packet_wait(&i2c_master_instance, &packet);
}

int tcpc_read(int port, int reg, int *val)
{
	uint8_t data[1];
	data[0] = (0xFF) & reg;
	
	struct i2c_master_packet packet;
	packet.address = tcpc_config[port].i2c_slave_addr;
	packet.data_length = 1;
	packet.data = data;
	packet.ten_bit_address = false;
	packet.high_speed = false;
	packet.hs_master_code = 0x00;
	
	enum status_code ret_code = i2c_master_write_packet_wait_no_stop(&i2c_master_instance, &packet);
	if (STATUS_OK != ret_code)
	{
		return ret_code;
	}

	packet.address = tcpc_config[port].i2c_slave_addr;
	packet.data_length = 1;
	packet.data = data;
	packet.ten_bit_address = false;
	packet.high_speed = false;
	packet.hs_master_code = 0x00;

	ret_code = i2c_master_read_packet_wait(&i2c_master_instance, &packet);
	if (STATUS_OK != ret_code)
	{
		return ret_code;
	}
	
	*val = data[0];
	
	return STATUS_OK;
}

int tcpc_read16(int port, int reg, int *val)
{
	uint8_t data[2];
	data[0] = (0xFF) & reg;
	
	struct i2c_master_packet packet;
	packet.address = tcpc_config[port].i2c_slave_addr;
	packet.data_length = 1;
	packet.data = data;
	packet.ten_bit_address = false;
	packet.high_speed = false;
	packet.hs_master_code = 0x00;
	
	enum status_code ret_code = i2c_master_write_packet_wait_no_stop(&i2c_master_instance, &packet);
	if (STATUS_OK != ret_code)
	{
		return ret_code;
	}

	packet.address = tcpc_config[port].i2c_slave_addr;
	packet.data_length = 2;
	packet.data = data;
	packet.ten_bit_address = false;
	packet.high_speed = false;
	packet.hs_master_code = 0x00;

	ret_code = i2c_master_read_packet_wait(&i2c_master_instance, &packet);
	if (STATUS_OK != ret_code)
	{
		return ret_code;
	}
	
	*val  = data[0];
	*val |= (data[1] << 8);
	
	return STATUS_OK;
}

int tcpc_xfer(int port,
	const uint8_t *out, int out_size,
	uint8_t *in, int in_size,
	int flags)
{
	struct i2c_master_packet packet;
	packet.address = tcpc_config[port].i2c_slave_addr;
	packet.data_length = out_size;
	packet.data = out;
	packet.ten_bit_address = false;
	packet.high_speed = false;
	packet.hs_master_code = 0x00;

	enum status_code ret_code;
	if (out_size != 0)
	{
		if (flags & I2C_XFER_STOP)
		{
			ret_code = i2c_master_write_packet_wait(&i2c_master_instance, &packet);
		}
		else
		{
			ret_code = i2c_master_write_packet_wait_no_stop(&i2c_master_instance, &packet);
		}
		if (STATUS_OK != ret_code)
		{
			return ret_code;
		}
	}

	packet.address = tcpc_config[port].i2c_slave_addr;
	packet.data_length = in_size;
	packet.data = in;
	packet.ten_bit_address = false;
	packet.high_speed = false;
	packet.hs_master_code = 0x00;

	if (in_size != 0)
	{
		// We always send a stop, then another start on the next call. 
		// This avoids trying to read after sending a NACK, which indicates the end of the read. 
		// In the future, this could be optimized by using lower level i2c calls. 
		ret_code = i2c_master_read_packet_wait(&i2c_master_instance, &packet);
		if (STATUS_OK != ret_code)
		{
			return ret_code;
		}
	}

	return STATUS_OK;
}

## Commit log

2017-11-19 Added missing Altium board file that got lost somehow
    [USB-C_Explorer.PcbDoc]
2018-01-09 Fixed USB PD communication
    Had to get it to increment the message ID on each sucessful message.
    [FUSB302.c, conf_board.h, main.c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]
2018-01-14 Fixed auto-reset bug
    Added a short delay in the initialization sequence to avoid the code
    always asking for a reset only outside the debugger.
    [FUSB302.c, main.c, tcpm_driver.c]
2018-01-14 Fixed High Voltage Failure
    Fixed bug that caused high voltages on VBUS to kill the regulator. Max
    VIN might be 40 V, but abs max on the EN pin is 6 V. The EN has an
    internal pull-up, so we can just disconnect it.
    [USB-C Explorer.PrjPcb, USB-C.SchDoc, USB-C_Explorer.PcbDoc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]
2018-01-14 Increased Max Power
2018-07-02 changed callback timing
    Had to move the callback call to after sending the request, due to some power supplies getting upset about it taking too long to write to the display.
2018-11-24 Added USB Battery Charging Spec support
2018-11-24 Prints a message on the second screen about Alt Mode. Just DisplayPort for now.
2018-11-25 fixed bug causing extra hard resets
    Added a delay in the tcpm_transmit() function in order to give the PHY a chance to receive the Good_CRC packet before it switches polarity. If we miss it, then there the message_id will not increment.
    [FUSB302.c]
2018-11-25 fixed screen-tearing bug
    if the user button was pushed while another thread was trying to update the screen, screen tearing could occur. Now the interrupt only notes that a change is needed, and the change is down in the main loop.
    [main.c]
2018-11-25 perfer higher voltage
2018-12-10 don't do PD before we're ready
    This line would cause the Source to think that we had power delivery capability before we intended to. Removing this line increases the stability of the firmware, albeit at the cost of a slightly slower timeline.
    [FUSB302.c]
2020-11-13 Stability upgrades
    Migrated to Microchip Studio (formerly Atmel Studio), I2C to 1 MHz, SPI uses DMA, Power Delivery code doesn't send Get_Source_Cap messages, screen update code optimized to bring response times in line with USB PD Spec, and other minor upgrades.
    [FUSB302.c, conf_ssd1306.h]
